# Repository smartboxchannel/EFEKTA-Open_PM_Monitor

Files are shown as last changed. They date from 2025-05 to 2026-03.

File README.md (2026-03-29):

# EFEKTA-Open_PM_Monitor

Описание: http://efektalab.com/Open_PM_Monitor

Поблагодарить автора: https://yoomoney.ru/fundraise/P2XLTgJsB6k.231012

Thank the author: https://yoomoney.ru/fundraise/P2XLTgJsB6k.231012

Телеграм чат DIY Devices - https://t.me/diy_devices

Продажа DIY Устройств - https://t.me/diydevmart

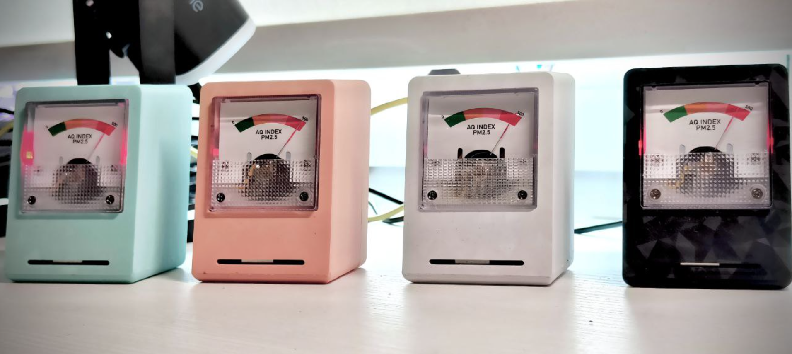
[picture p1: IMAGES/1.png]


Проект датчика мониторинга твердых частиц (PM1.0, PM2.5, PM10, PM2.5 Index, (с версии 2.0 TVOC, eCO2, AQI)) с аналоговым стрелочным дисплеем, Zigbee 3.0. Датчик является роутером сети.

Project of particle monitoring sensor (PM1.0, PM2.5, PM10, PM2.5 Index, (from version 2.0 TVOC, eCO2, AQI)) with analog pointer display, Zigbee 3.0. The sensor is a network router.

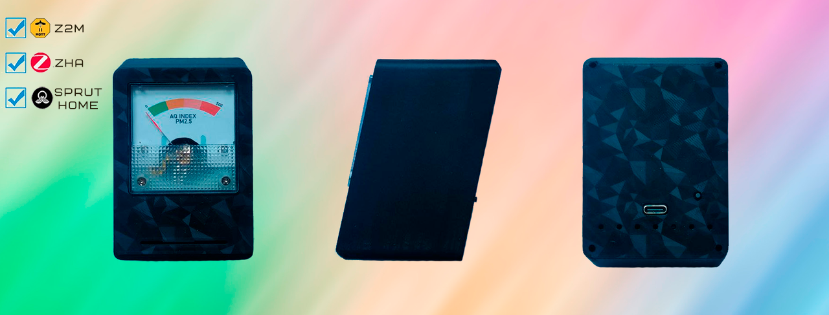
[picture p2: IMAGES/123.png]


Сенсор твердых частиц, помимо данных PM2.5, также измеряет PM1, PM10 и рассчитывает PM2.5 Index. Проект сделан на основе сенсора ASAIR APM10.

The particle sensor, in addition to PM2.5 data, also measures PM1, PM10 and calculates PM2.5 Index. The project is based on the ASAIR APM10 sensor.

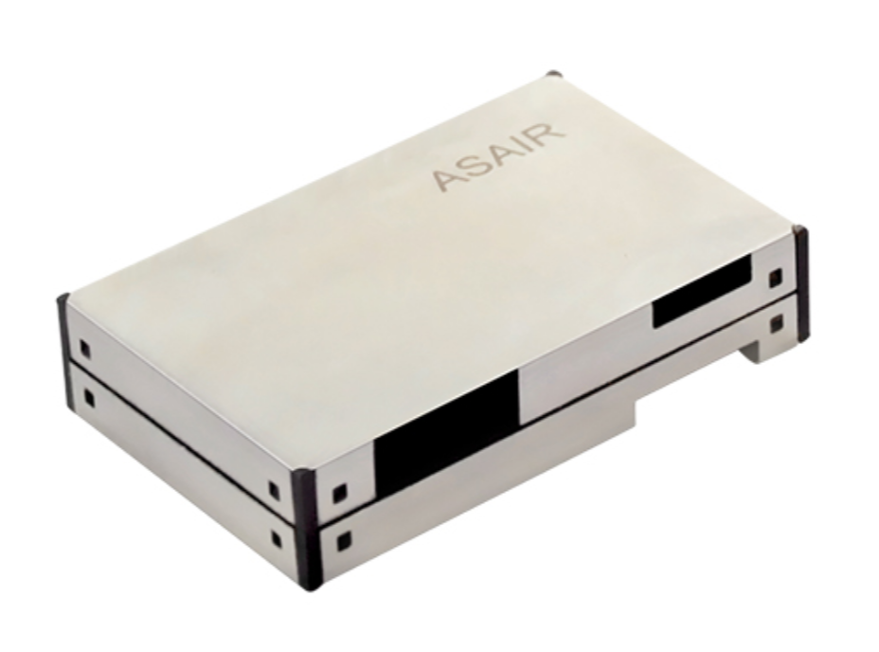
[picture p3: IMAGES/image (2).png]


Помимо стрелочной индикации, есть светодиодная индикация, которая отображает визуально уровень PM2.5 Index. Яркость светодиодов подсветки можно настраивать удалённо. Подсветку также можно отключить удалённо.

In addition to the arrow indication, there is an LED indication that visually displays the PM2.5 Index level. The brightness of the backlight LEDs can be adjusted remotely. The backlight can also be turned off remotely.

#

### Версия 2.0

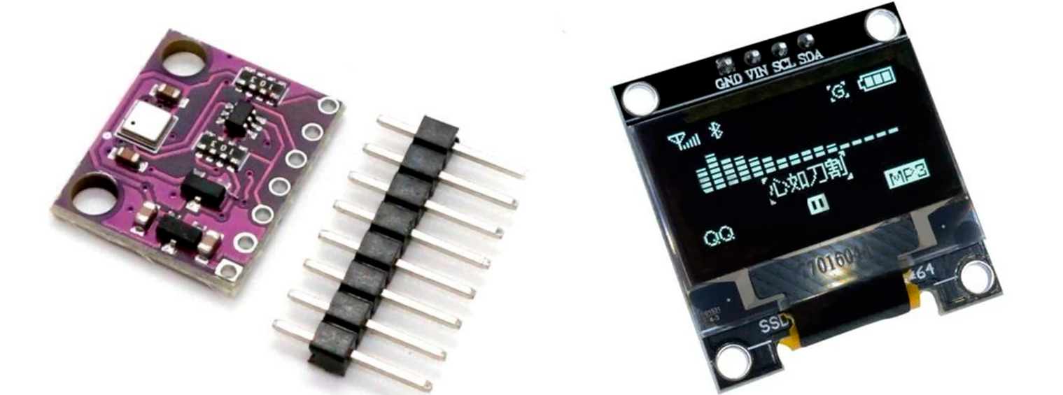
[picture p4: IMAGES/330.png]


В обновленную версию добавлен oled дисплей и сенсор ENS160 (TVOC, eCO2, AQI). Реализовано автоматическое детектирование наличия дисплея и сенсора ENS160, если не подключено что то из этого, работа с дисплеем или сенсором пропускается в ПО. Если подключен сенсор ENS160, на дисплее поочередно выводятся данные PM2.5, TVOC, eCO2. Если сенсор не подключен то выводятся толко данные PM2.5

The updated version includes an OLED display and an ENS160 sensor (TVOC, eCO2, AQI). Automatic detection of the presence of the ENS160 display and sensor has been implemented. If neither of these is connected, operation with the display or sensor is skipped in the software. If the ENS160 sensor is connected, the display alternates between PM2.5, TVOC, and eCO2. If the sensor is not connected, only PM2.5 data is displayed.

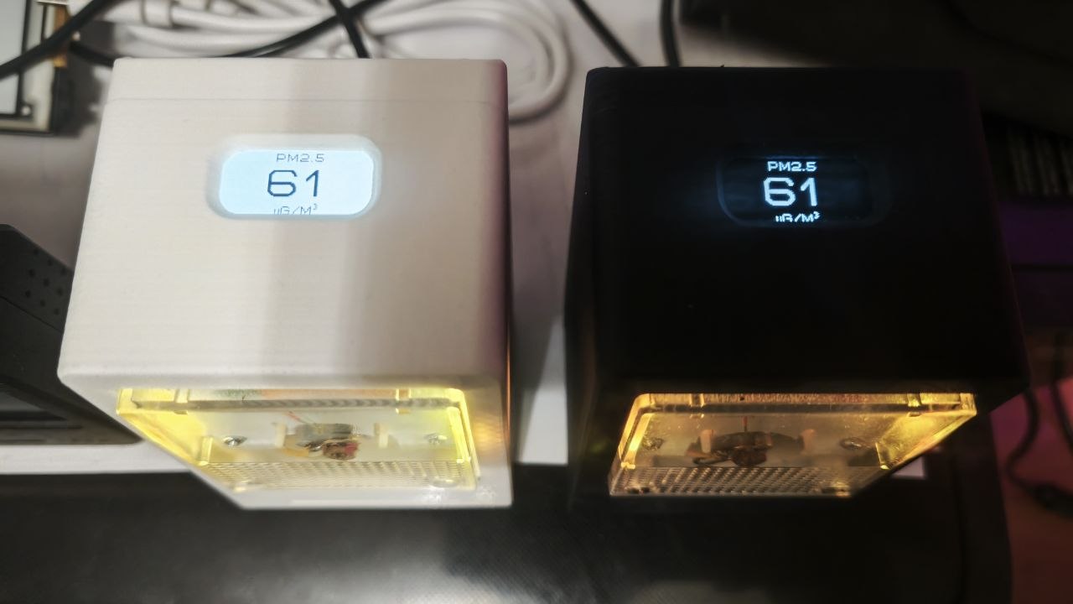
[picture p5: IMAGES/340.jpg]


Добавлена поддержка альтернативного датчика PM того же производителя  - APM2000. В ПО реализовано атоматическое детектирование подключенного сенсора PM.

Added support for an alternative PM sensor from the same manufacturer—the APM2000. The software implements automatic detection of the connected PM sensor.

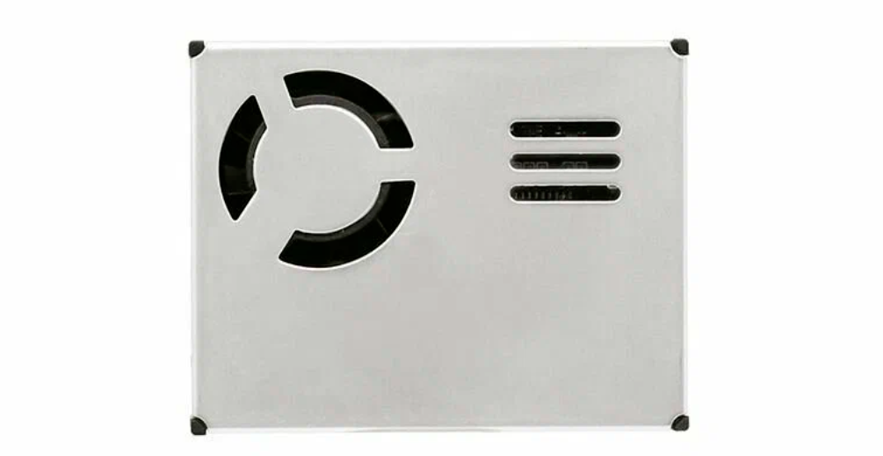
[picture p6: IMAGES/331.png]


## OTA

Датчик может обновляться новыми версиями прошивок по воздуху (OTA).

The sensor can be updated with new firmware versions over the air (OTA). 

( https://github.com/koptserg/OTAClient )

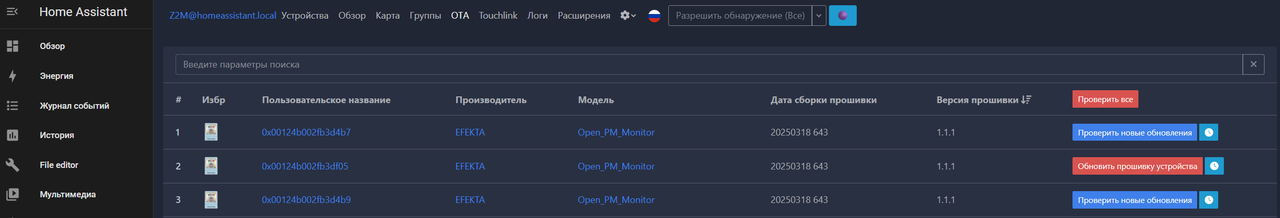
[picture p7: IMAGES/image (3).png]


## Основные данные:

- Identify - идентификация устройства

- State - включение/отключение подсветки

- Brightness - яркость подсветки

- Pm1 - уровень твердых частиц размером 1 мкм и менее

- Pm2.5 - уровень твердых частиц размером 2.5 мкм и менее

- Pm10 - уровень твердых частиц размером 10 мкм и менее

- Aqi25 - индекс качества воздуха на основе PM2.5 (EPA)

- Tvoc - уровень летучих органических соединений

- eCO2 - уровень эквивалента углекислого газа

- AQI - уровень загрязнения воздуха

## Basic data:

- Identify - device identification

- State - backlight on/off

- Brightness - backlight brightness

- Pm1 - particulate matter level of 1 µm or less

- Pm2.5 - particulate matter level of 2.5 µm or less

- Pm10 - particulate matter level of 10 µm or less

- Aqi25 - air quality index based on PM2.5 (EPA)

- Tvoc - Volatile Organic Compounds (VOC)

- eCO2 - Carbon Dioxide Equivalent (CO2)

- AQI - Air Quality Index (AQI)

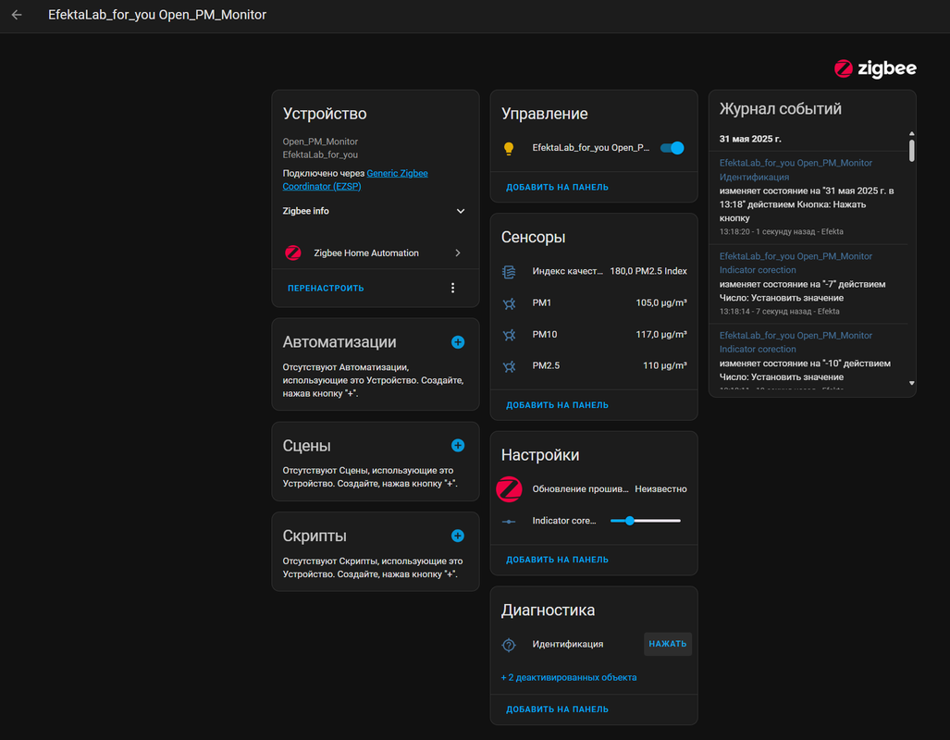
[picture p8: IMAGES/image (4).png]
  

## Конфигурационные данные:

- Indicator correction - подстройка стрелочного индикатора

- Invert color - инвертирование oled дисплея

## Configuration data:

- Indicator correction - adjustment of the arrow indicator

- Invert color - inverting the OLED display

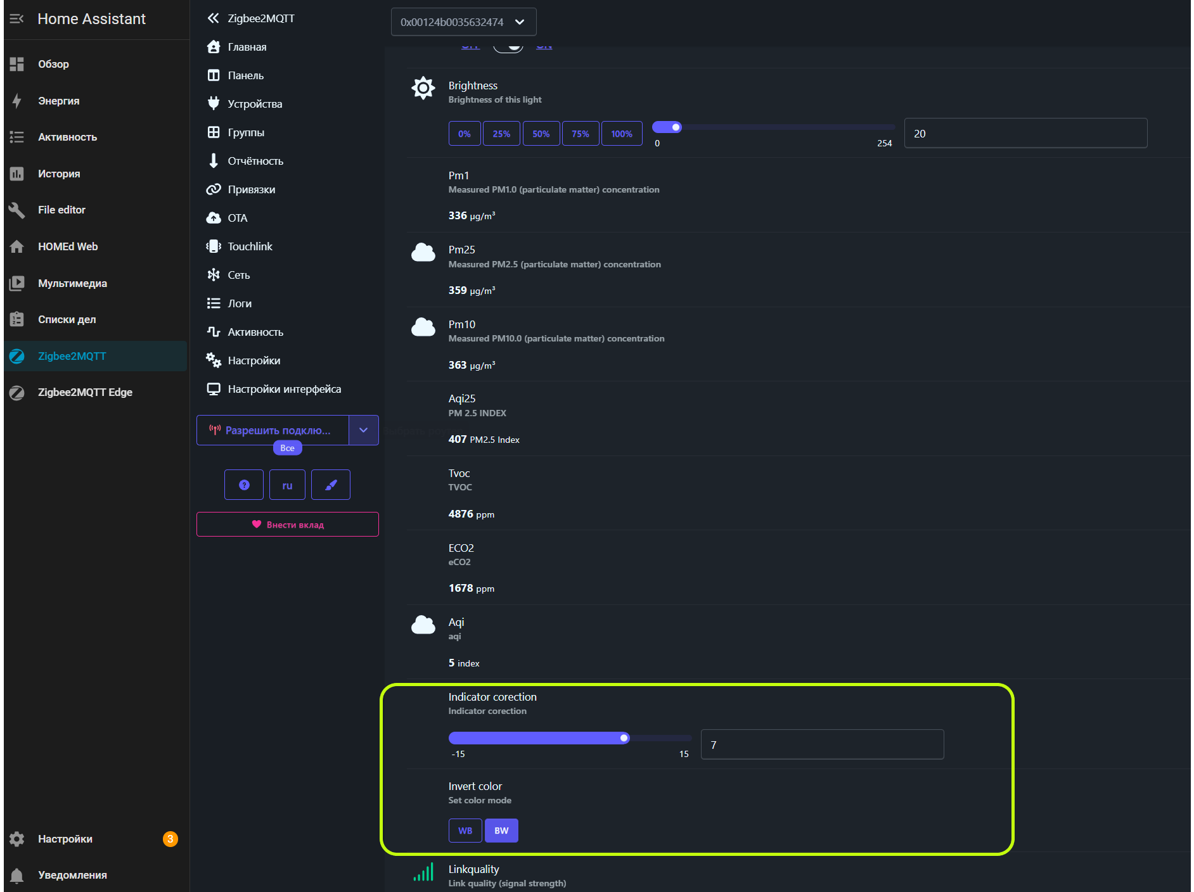
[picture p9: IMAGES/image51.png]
  

## Ввод датчика в сеть, выход из сети

Для джойна (вход в сеть) включите джойн, зажмите и удерживайте кнопку сбоку датчика. С задней стороны датчика загорится системный светодиод (примерно на 3-5 секунд при успешном поиске открытой сети, 15 секунд при неудачном поиске открытой сети).

Если вы не видите на вкладке "Свойства" всех значений конфигурационных атрибутов (пустые поля, переключатели в неопределённом состоянии) или на вкладке "Отчёты" нет заполненных строк о типах данных PM и т.д., то скорее всего конфигурация, которая следует сразу за интервью, не была пройдена до конца.

Для повторного прохождения конфигурации перейдите на главную страницу z2m, найдите строку датчика и справа нажмите на кнопку "Реконфигурация" (жёлтая кнопка), после этого несколько раз нажмите на кнопку джойстик сбоку - это вызовет отправку всех основных и конфигурационных данных. При успешном прохождении конфигурации в интерфейсе z2m должно появиться всплывающее сообщение об успешно пройденной реконфигурации. В разделе датчика на вкладке "Свойства" должны появиться значения и установки всех конфигурационных свойств, на странице "Отчёты" должны появиться строки с конфигурационными настройками отчётов.

Когда датчик в сети, то короткое нажатие на кнопку вызывает процедуру чтения всех сенсоров не по расписанию и отправку данных не в режиме настроенных отчётов.

Для выхода из сети зажмите кнопку на 10 секунд. С задней стороны датчика начнёт мигать системный светодиод (частота переключения LED - 1 секунда). Когда светодиод перестанет мигать, кнопку можно отпустить. Датчик отправит сообщение о выходе из сети, сотрёт у себя все настройки в памяти.

Также выйти из сети можно, удалив датчик из z2m без опции "force remove".

## Entering the sensor into the network, leaving the network

For joining (entering the network), turn on the join, press and hold the button on the side of the sensor. The system LED on the back of the sensor will light up (for about 3-5 seconds if the search for an open network is successful, 15 seconds if the search for an open network is unsuccessful).

If you do not see all the values of the configuration attributes on the "Properties" tab (empty fields, switches in an undefined state) or there are no filled lines on the "Reports" tab about the PM data types, etc., then most likely the configuration that immediately follows the interview was not completed.

To repeat the configuration, go to the main page of z2m, find the sensor line and click on the "Reconfiguration" button on the right (yellow button), then press the joystick button on the side several times - this will cause all the main and configuration data to be sent. If the configuration is successful, a pop-up message about the successful reconfiguration should appear in the z2m interface. In the sensor section, on the "Properties" tab, the values and settings of all configuration properties should appear, and on the "Reports" page, lines with the configuration settings of reports should appear.

When the sensor is online, a short press on the button causes the procedure of reading all sensors not according to the schedule and sending data not in the configured reports mode.

To exit the network, hold the button for 10 seconds. The system LED on the back of the sensor will start blinking (LED switching frequency is 1 second). When the LED stops blinking, you can release the button. The sensor will send a message about leaving the network, erasing all settings in its memory.

You can also exit the network by deleting the sensor from z2m without the "force remove" option.

# Цветовая индикация 

## Индекс качества воздуха на основе PM2.5:

- < 120 - зелёный
- ≥120 < 250 - жёлтый
- ≥250 < 380 - розовый
- ≥380 - красный

# Color indication

## Air quality index based on PM2.5:

- < 120 - green
- ≥120 < 250 - yellow
- ≥250 < 380 - pink
- ≥380 - red

# Обновление ПО (OTA):

Прошивка устройства может быть обновлена. Если для датчика доступно обновление, то необходимо активировать загрузку обновления.

## Если обновление еще не доступно в zigbee2mqtt

Для добавления нового обновления в z2m в "ручную" необходимо:

1. Загрузить в папку zigbee2mqtt файл обновления для датчика, пример /zigbee2mqtt/5678-1000-10063202.zigbee

2. Создать файл ota_index.json с содержанием:

[

  {

    "url": "5678-1000-10063202.zigbee"

  }

]

3. Загрузить файл ota_index.json в папку zigbee2mqtt

4. Перезагрузить zigbee2mqtt

# Software update (OTA):

The device firmware can be updated. If an update is available for the sensor, you must activate the update download.

## If the update is not yet available in zigbee2mqtt

To add a new update to z2m "manually" you need to:

1. Upload the update file for the sensor to the zigbee2mqtt folder, example /zigbee2mqtt/5678-1000-10063202.zigbee

2. Create the ota_index.json file with the content:

[

{

"url": "5678-1000-10063202.zigbee"

}

]

3. Upload the ota_index.json file to the zigbee2mqtt folder

4. Restart zigbee2mqtt

#

### Установка среды разработки

В качестве среды разработки будет использоваться IAR Embedded Workbench, где цифра 8051 это архитектура чипа, а не версия системы, как можно подумать. Для начала необходимо ее [скачать по ссылке](https://www.iar.com/iar-embedded-workbench#!?architecture=8051)

MODKAM Flower 

Запускаем, необходимо выбрать пункт "Install IAR Embedded Workbench® for 8051"

MODKAM Flower 

При установке iar надо выбрать режим custom:

MODKAM Flower 

и убрать галочку с установки Dongle drivers

MODKAM Flower 

При попытки запуска проекта может быть такая ошибка:

MODKAM Flower 

Поэтому перед запуском проекта необходимо убедиться что python установлен. Проверить это можно в командной строке:

python –-version

MODKAM Flower 

Если все хорошо, то покажет текущую установленную версию python, как на примере:

MODKAM Flower 

Если же нет, то [идем устанавливать python](https://www.python.org/)

MODKAM Flower 

Устанавливаем его. Обязательно необходимо проставить галочку "add python **** to path"

MODKAM Flower 

Устанавливаем прошивку [Z-Stack 3.0.2](https://www.ti.com/tool/Z-STACK) — это SDK для разработки прошивок.

MODKAM Flower 

Устанавливаем, можно немного уменьшить путь до zstack: C:\Z-Stack 3.0.2. 

Скачиваем исходный код из репозитория

Добавляем папку с файлами проекта в zstack: C:\Z-Stack 3.0.2\Projects\zstack\HomeAutomation

Теперь можно запускать IAR Embedded Workbench. Открываем проект пунктом меню Open workspace

MODKAM Flower 

Находим нашу папку со скаченным проектом, далее в папке CC2530DB находим файл проекта

MODKAM Flower 

Выполняем Rebuild All.

MODKAM Flower 

#

### Как прошить устройство

Скачайте Smart RF Flash Programmer V1 https://www.ti.com/tool/FLASH-PROGRAMMER

Откройте приложение, выберите HEX-файл прошивки

Подключите устройство проводами к CCDebugger, сначала сотрите данные с чипа, затем прошейте его.

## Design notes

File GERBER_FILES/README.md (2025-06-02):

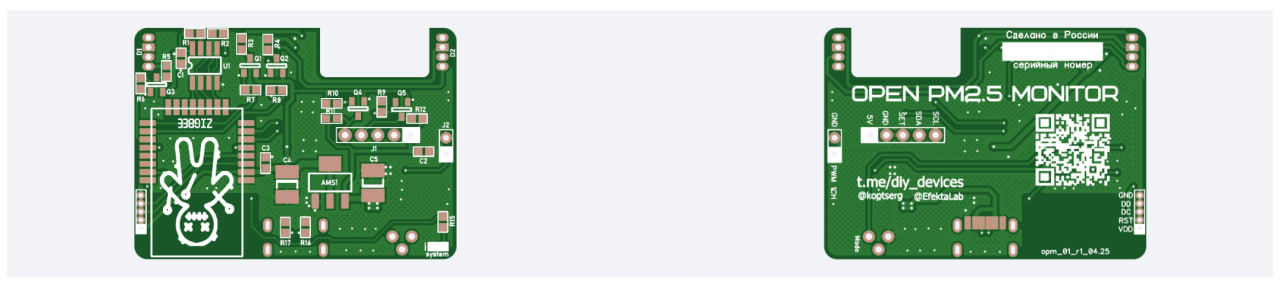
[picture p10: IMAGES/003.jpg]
EFEKTA Open PM Monitor


### pcb 1.6mm

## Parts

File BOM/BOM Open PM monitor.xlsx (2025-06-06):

Comment | Designator | АлиЭкспресс | Zigbee-Shop
M25PE20-VMN6TP | U1 | https://aliexpress.ru/item/1005008415017340.html
E18-MS1PA2-IPX | U2 | https://aliexpress.ru/item/4000818220197.html | Беспроводной модуль EBYTE E18-MS1PA2-IPEX ZigBee - ZigBee-Shop.ru (https://zigbee-shop.ru/catalog/goods/1444)
AMS1117 | U3 | https://aliexpress.ru/item/1005008229056966.html | Стабилизатор AMS1117 3.3V - ZigBee-Shop.ru (https://zigbee-shop.ru/catalog/goods/1132)
100NF 0603 | C1, C2, С3 | https://aliexpress.ru/item/1005002063634783.html | Чип конденсатор (SMD) 0603 100NF 0.1uF - ZigBee-Shop.ru (https://zigbee-shop.ru/catalog/goods/1548)
51Ω 0603 | R3 | https://aliexpress.ru/item/1005008917262490.html | Чип резистор (SMD) 0603 51R, 1% - ZigBee-Shop.ru (https://zigbee-shop.ru/catalog/goods/1794)
200Ω 0603 | R5 | https://aliexpress.ru/item/32997843929.html | Чип резистор (SMD) 0603 200R, 5% - ZigBee-Shop.ru (https://zigbee-shop.ru/catalog/goods/1754)
470Ω 0603 | R4 | https://aliexpress.ru/item/1005001793580277.html | Чип резистор (SMD) 0603 470R, 5% - ZigBee-Shop.ru (https://zigbee-shop.ru/catalog/goods/1544)
1KΩ 0603 | R5, R7, R8 | https://aliexpress.ru/item/1005008633246937.html | Чип резистор (SMD) 0603 1K, 5% - ZigBee-Shop.ru (https://zigbee-shop.ru/catalog/goods/1210)
2KΩ 0603 | R1, R2 | https://aliexpress.ru/item/1005008810795724.html | Чип резистор (SMD) 0603 2.4K, 5% - ZigBee-Shop.ru (https://zigbee-shop.ru/catalog/goods/1212)
4.2KΩ 0603 | R15 | https://aliexpress.ru/item/1005008533807204.html | Чип резистор (SMD) 0603 4.7K, 5% - ZigBee-Shop.ru (https://zigbee-shop.ru/catalog/goods/1211)
5.1KΩ 0603 | R16, R17 | https://aliexpress.ru/item/1005004538763316.html | Чип резистор (SMD) 0603 5.1K, 5% - ZigBee-Shop.ru (https://zigbee-shop.ru/catalog/goods/1546)
10KΩ 0603 | R9, R10, R11, R12 | https://aliexpress.ru/item/1005004541262069.html | Чип резистор (SMD) 0603 10K, 5% - ZigBee-Shop.ru (https://zigbee-shop.ru/catalog/goods/1545)
TCAP 22UF | C4, C5 | https://aliexpress.ru/item/1005008695997250.html | Танталовый конденсатор 22UF 16V CASE-B TAJB226K016RNJ - ZigBee-Shop.ru (https://zigbee-shop.ru/catalog/goods/1178)
USB C 6P | U2 | https://aliexpress.ru/item/1005006047551075.html | Разъем TYPE-C 6 Pin SMT - ZigBee-Shop.ru (https://zigbee-shop.ru/catalog/goods/1539)
S8050 | Q1, Q2, Q3 | https://aliexpress.ru/item/1005008535311819.html | Транзистор SS8050, NPN 25V 1.5A [SOT-23] - ZigBee-Shop.ru (https://zigbee-shop.ru/catalog/goods/1288)
RGB Common Cathode | D1, D2 | https://aliexpress.ru/item/1005003168998839.html
BSS138 | Q4, Q5 | https://aliexpress.ru/item/1005008321377755.html | Транзистор BSS138W, N-канал, 50В, 0.22А [SOT-323] - ZigBee-Shop.ru (https://zigbee-shop.ru/catalog/goods/1921)
Switch 4.5x4.5 8mm | KEY1 | https://aliexpress.ru/item/1005007935339142.html
Led 0604 | LED1 | https://aliexpress.ru/item/1005003523838944.html
Voltmeter 3V |  | https://aliexpress.ru/item/32617041101.html
PM ASAIR APM10 |  | https://aliexpress.ru/item/1005006514171610.html
Антенна 2.4 IPEX |  | https://aliexpress.ru/item/1005005324850574.html | Антенна липучка IPEX 10 см - ZigBee-Shop.ru (https://zigbee-shop.ru/catalog/goods/1653)
Саморезы M1.4 5мм |  | https://aliexpress.ru/item/32835249403.html

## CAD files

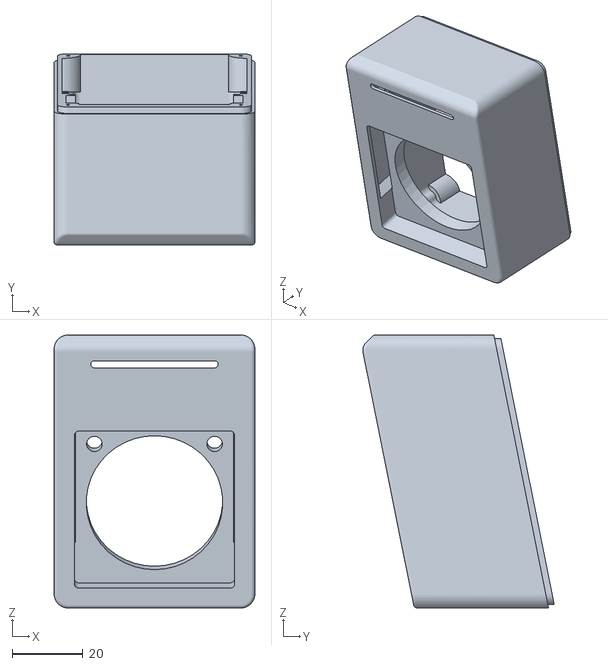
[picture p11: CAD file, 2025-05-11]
ENCLOUSER/1.stl
56.8 x 54.1 x 77.2

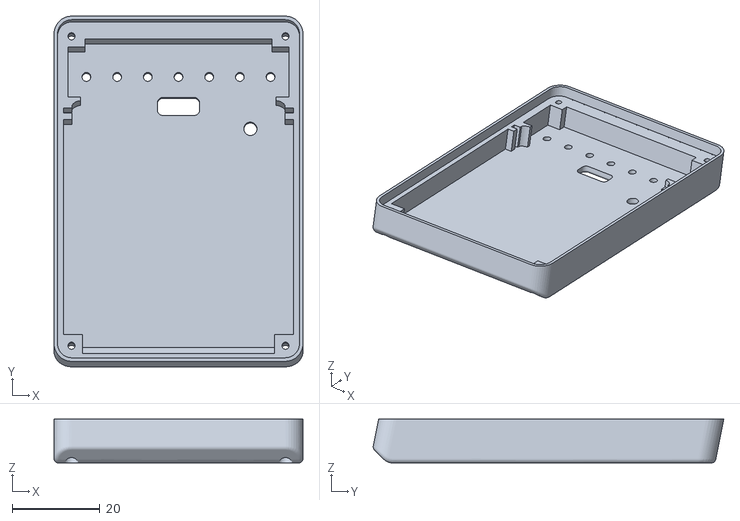
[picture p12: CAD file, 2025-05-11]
ENCLOUSER/2.stl
56.8 x 80.0 x 10.0

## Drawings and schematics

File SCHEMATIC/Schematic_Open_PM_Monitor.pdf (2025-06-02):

## R8PWM³Ch

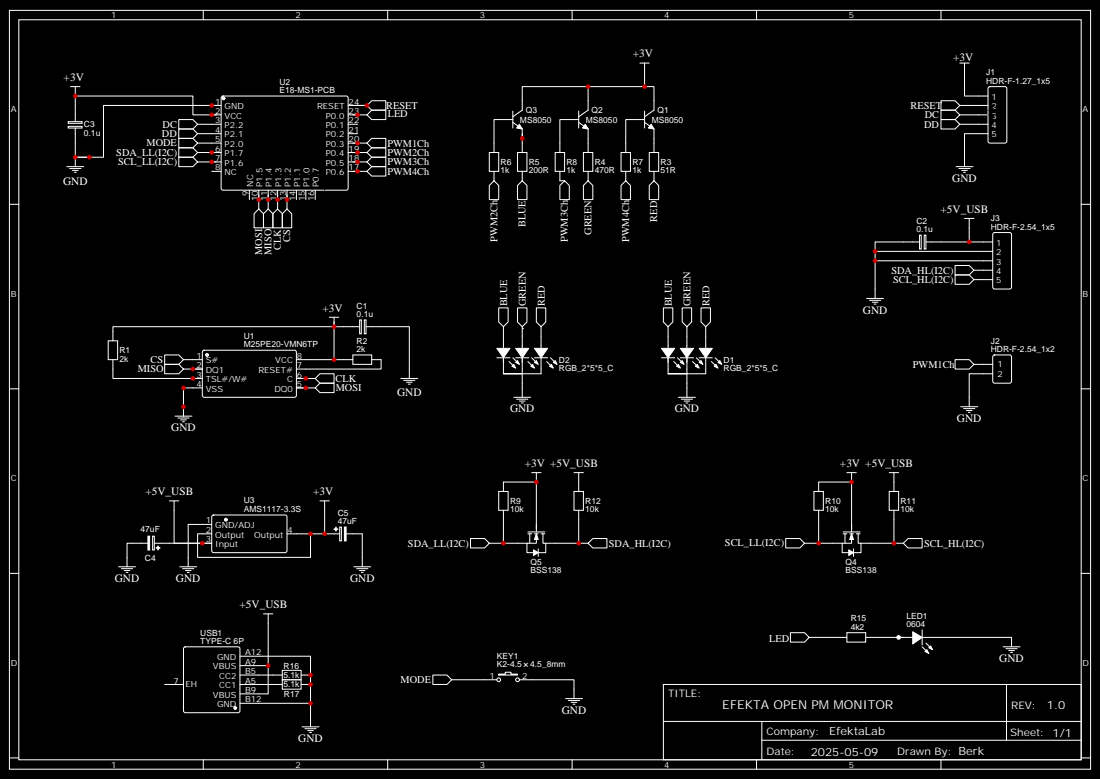
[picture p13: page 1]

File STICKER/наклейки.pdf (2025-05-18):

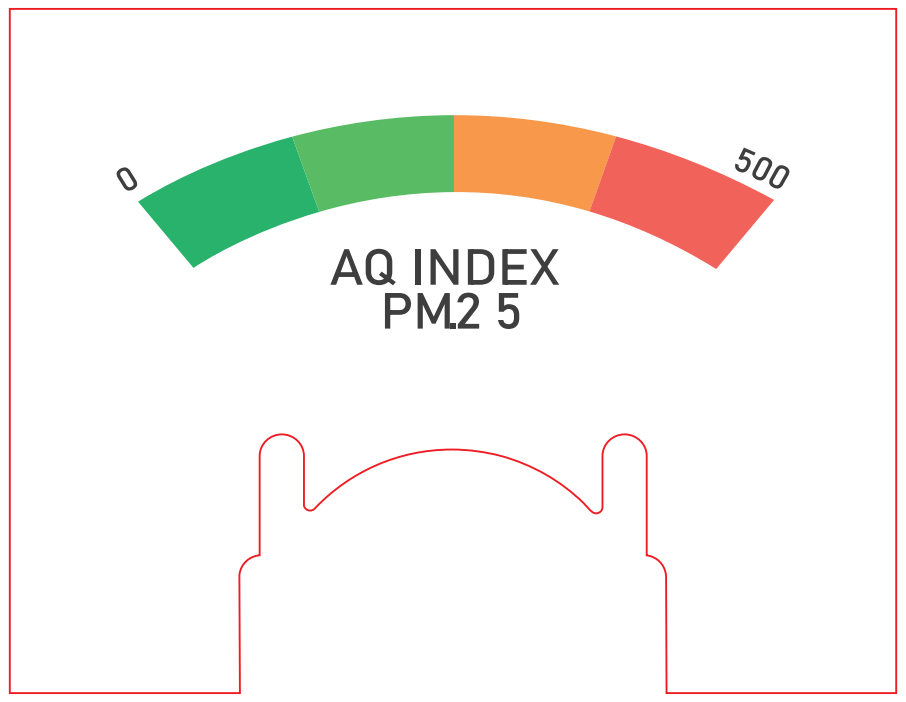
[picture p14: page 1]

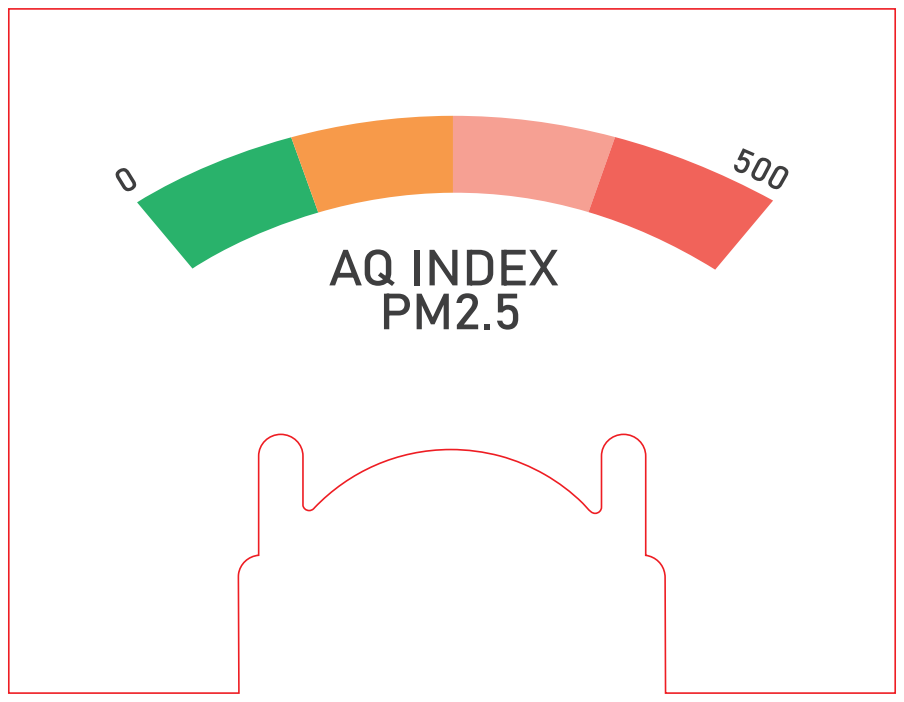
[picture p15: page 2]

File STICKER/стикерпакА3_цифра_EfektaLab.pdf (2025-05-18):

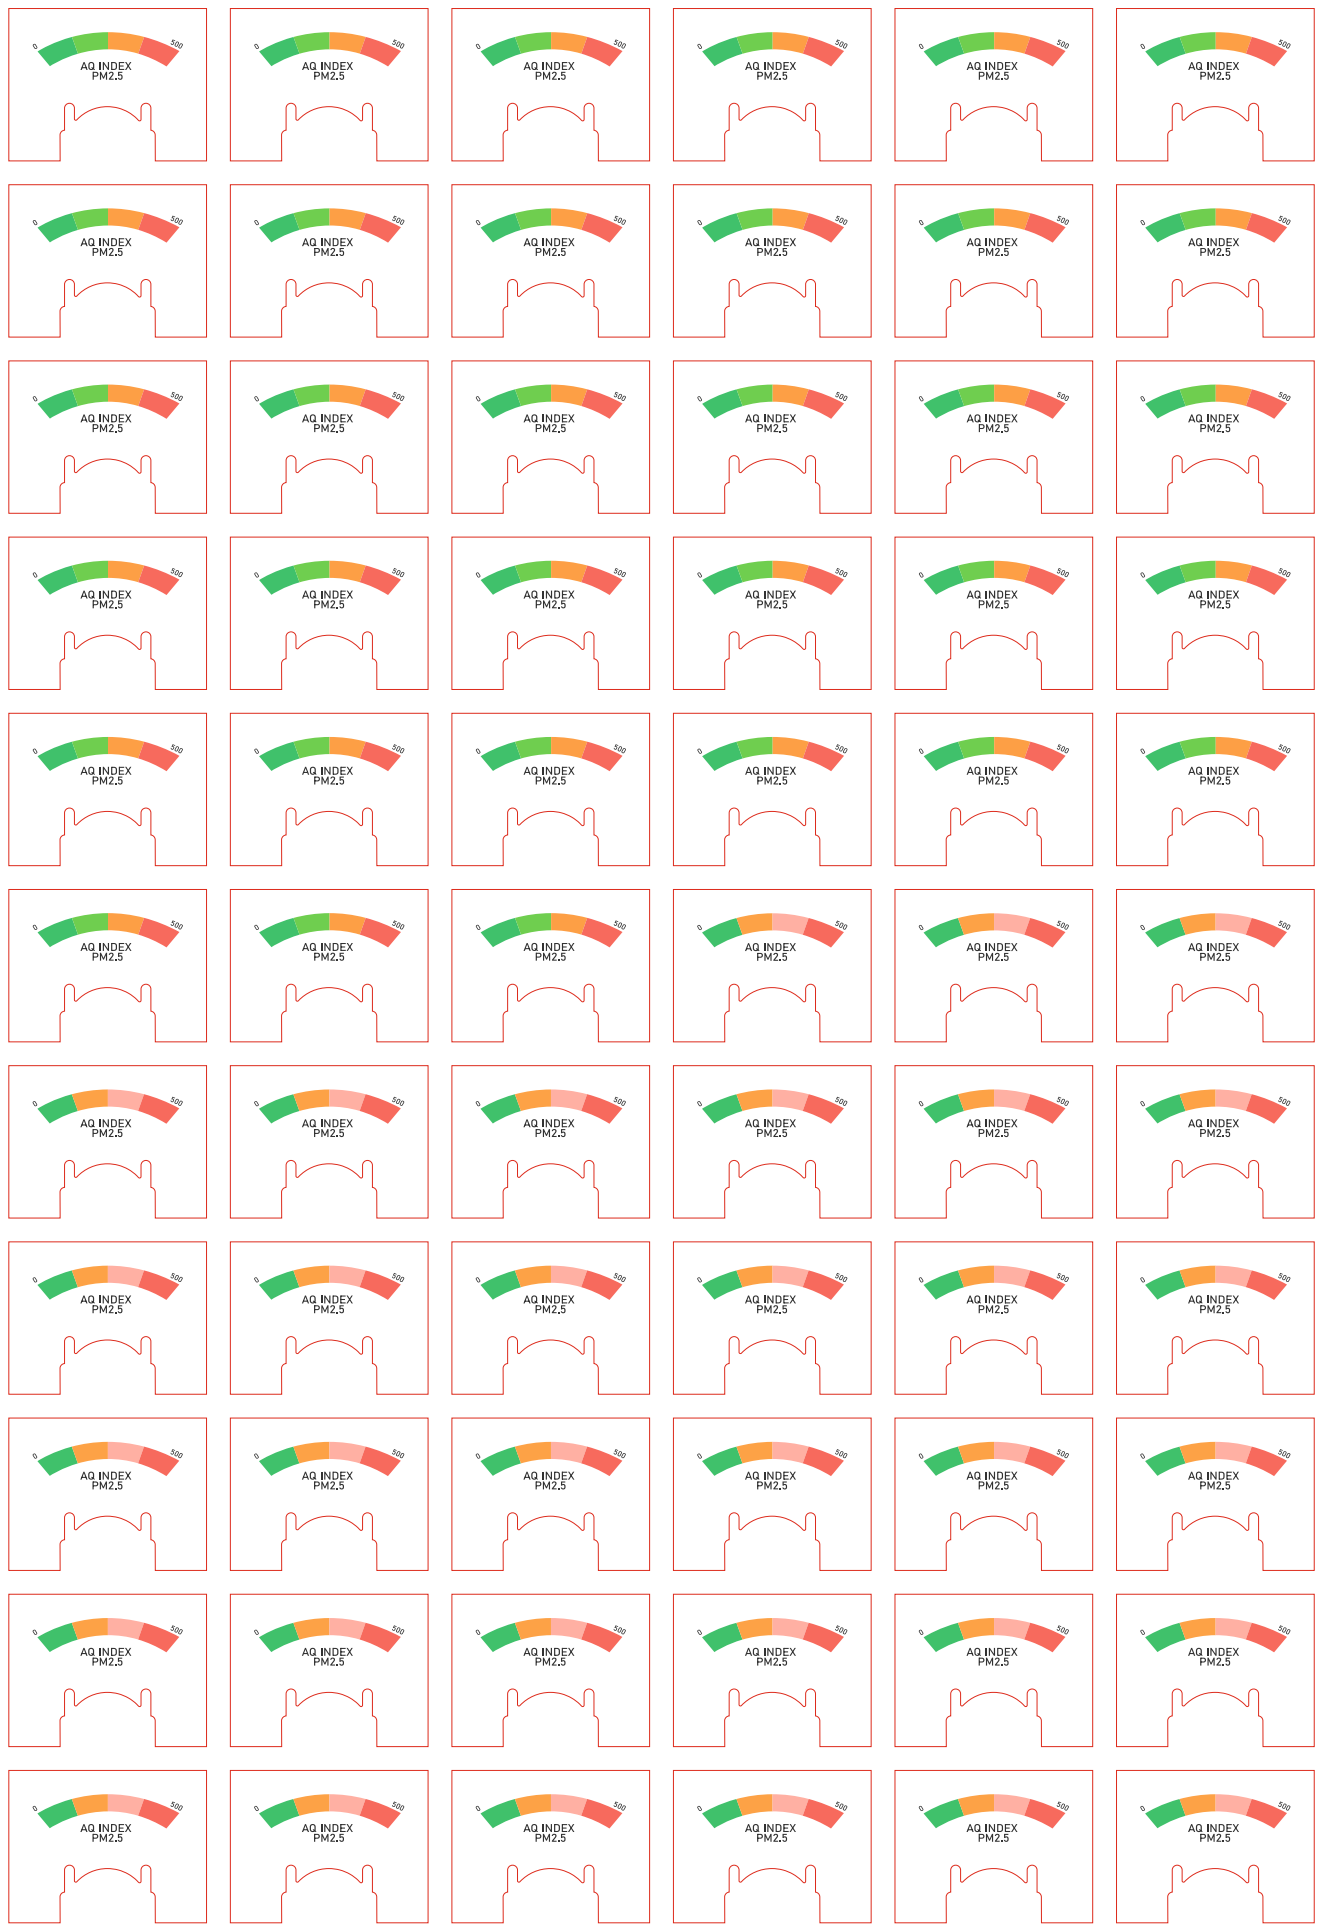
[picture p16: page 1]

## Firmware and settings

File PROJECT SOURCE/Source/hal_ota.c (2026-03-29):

/******************************************************************************
  Filename:       hal_ota.c
  Revised:        $Date: 2010-11-18 08:22:50 -0800 (Thu, 18 Nov 2010) $
  Revision:       $Revision: 24438 $

  Description:    This module contains optionally-compiled Boot Code to support
                  OTA. The rest of the functionality is the H/W specific drivers
                  to read/write the flash/NV containing the ACTIVE and the
                  DOWNLOADED images.
  Notes:          Targets the Texas Instruments CC253x family of processors.


  Copyright 2010 Texas Instruments Incorporated. All rights reserved.

  IMPORTANT: Your use of this Software is limited to those specific rights
  granted under the terms of a software license agreement between the user
  who downloaded the software, his/her employer (which must be your employer)
  and Texas Instruments Incorporated (the "License").  You may not use this
  Software unless you agree to abide by the terms of the License. The License
  limits your use, and you acknowledge, that the Software may not be modified,
  copied or distributed unless embedded on a Texas Instruments microcontroller
  or used solely and exclusively in conjunction with a Texas Instruments radio
  frequency transceiver, which is integrated into your product.  Other than for
  the foregoing purpose, you may not use, reproduce, copy, prepare derivative
  works of, modify, distribute, perform, display or sell this Software and/or
  its documentation for any purpose.

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
  Should you have any questions regarding your right to use this Software,
  contact Texas Instruments Incorporated at www.TI.com.
******************************************************************************/

/******************************************************************************
 * INCLUDES
 */
#include "comdef.h"
#include "hal_board_cfg.h"
#include "hal_dma.h"
#include "hal_flash.h"
#include "hal_ota.h"
#include "hal_types.h"

#include "ota_common.h"

//#include "Debug.h"
#include "OSAL.h"
/******************************************************************************
 * CONSTANTS
 */
#if HAL_OTA_XNV_IS_SPI
/*
#define XNV_STAT_CMD  0x05
#define XNV_WREN_CMD  0x06
#define XNV_WRPG_CMD  0x0A
//#define XNV_WRPG_CMD  0x02
#define XNV_READ_CMD  0x0B //READ DATA BYTES at HIGHER SPEED
//#define XNV_READ_CMD  0x03 //READ DATA BYTES
#define XNV_STAT_WIP  0x01
#define XNV_BE_CMD    0xC7
*/
#define XNV_STAT_CMD  0x05
#define XNV_WREN_CMD  0x06
#define XNV_WRPG_CMD  0x02
#define XNV_READ_CMD  0x0B //READ DATA BYTES at HIGHER SPEED
#define XNV_STAT_WIP  0x00
#define XNV_BE_CMD    0xC7
#define XNV_SE_CMD    0x20 // SECTOR ERASE 4K

#define ERASE_SECTOR_SIZE 0x1000  // 4 KB

static uint32 lastErased = 0xFFFFFFFF;
#endif

/******************************************************************************
 * TYPEDEFS
 */
typedef struct
{
  uint16 crc[2];
  uint32 programSize;
} OTA_CrcControl_t;

/******************************************************************************
 * LOCAL VARIABLES
 */
OTA_CrcControl_t OTA_crcControl;

#if HAL_OTA_BOOT_CODE
halDMADesc_t dmaCh0;
#endif

/******************************************************************************
 * LOCAL FUNCTIONS
 */
static uint16 runPoly(uint16 crc, uint8 val);

#if HAL_OTA_XNV_IS_SPI
static void HalSPIRead(uint32 addr, uint8 *pBuf, uint16 len);
static void HalSPIWrite(uint32 addr, uint8 *pBuf, uint16 len);
static void xnvSPIWrite(uint8 ch);
static void HalSPIEraseSector4K(uint32 addr);
static void DelayMs(uint16 delaytime);
#endif


#if HAL_OTA_BOOT_CODE
static void dl2rc(void);
static uint16 crcCalc(void);

/******************************************************************************
 * @fn      main
 *
 * @brief   ISR for the reset vector.
 *
 * @param   None.
 *
 * @return  None.
 */
#pragma location="NEAR_CODE"
void main(void)
{
  HAL_BOARD_INIT();
#if HAL_OTA_XNV_IS_SPI
  XNV_SPI_INIT();
#endif
  /* This is in place of calling HalDmaInit() which would require init of the
   * other 4 DMA descriptors in addition to just Channel 0.
   */
  HAL_DMA_SET_ADDR_DESC0( &dmaCh0 );

  while (1)
  {
    HalFlashRead(HAL_OTA_CRC_ADDR / HAL_FLASH_PAGE_SIZE,
                 HAL_OTA_CRC_ADDR % HAL_FLASH_PAGE_SIZE,
                 (uint8 *)&OTA_crcControl, sizeof(OTA_crcControl));

    if (OTA_crcControl.crc[0] == OTA_crcControl.crc[1])
    {
      break;
    }
    else if ((OTA_crcControl.crc[0] != 0) && (OTA_crcControl.crc[0] == crcCalc()))
    {
      OTA_crcControl.crc[1] = OTA_crcControl.crc[0];
      HalFlashWrite((HAL_OTA_CRC_ADDR / HAL_FLASH_WORD_SIZE), (uint8 *)OTA_crcControl.crc, 1);
    }
    else
    {
      dl2rc();
    }
  }

  // Simulate a reset for the Application code by an absolute jump to location 0x0800.
  asm("LJMP 0x800\n");
}

/******************************************************************************
 * @fn      dl2rc
 *
 * @brief   Copy the DL image to the RC image location.
 *
 *  NOTE:   Assumes that DL image ends on a flash word boundary.
 *
 * @param   None.
 *
 * @return  None.
 */
static void dl2rc(void)
{
  uint32 oset;
  OTA_SubElementHdr_t subElement;
  OTA_ImageHeader_t header;
  uint16 addr = HAL_OTA_RC_START / HAL_FLASH_WORD_SIZE;
  uint8 buf[4];

  // Determine the length and starting point of the upgrade image
  HalOTARead(0, (uint8 *)&header, sizeof(OTA_ImageHeader_t), HAL_OTA_DL);
  HalOTARead(header.headerLength, (uint8*)&subElement, OTA_SUB_ELEMENT_HDR_LEN, HAL_OTA_DL);

  for (oset = 0; oset < subElement.length; oset += HAL_FLASH_WORD_SIZE)
  {
    HalOTARead(oset + header.headerLength + OTA_SUB_ELEMENT_HDR_LEN, buf, HAL_FLASH_WORD_SIZE, HAL_OTA_DL);
    if ((addr % (HAL_FLASH_PAGE_SIZE / HAL_FLASH_WORD_SIZE)) == 0)
    {
      HalFlashErase(addr / (HAL_FLASH_PAGE_SIZE / HAL_FLASH_WORD_SIZE));
    }
    HalFlashWrite(addr++, buf, 1);
  }
}

/******************************************************************************
 * @fn      crcCalc
 *
 * @brief   Run the CRC16 Polynomial calculation over the RC image.
 *
 * @param   None.
 *
 * @return  The CRC16 calculated.
 */
static uint16 crcCalc()
{
  uint32 oset;
  uint16 crc = 0;

  // Run the CRC calculation over the active body of code.
  for (oset = 0; oset < OTA_crcControl.programSize; oset++)
  {
    if ((oset < HAL_OTA_CRC_OSET) || (oset >= HAL_OTA_CRC_OSET + 4))
    {
      uint8 buf;
      HalOTARead(oset, &buf, 1, HAL_OTA_RC);
      crc = runPoly(crc, buf);
    }
  }

  return crc;
}
#endif //HAL_OTA_BOOT_CODE

/******************************************************************************
 * @fn      runPoly
 *
 * @brief   Run the CRC16 Polynomial calculation over the byte parameter.
 *
 * @param   crc - Running CRC calculated so far.
 * @param   val - Value on which to run the CRC16.
 *
 * @return  crc - Updated for the run.
 */
static uint16 runPoly(uint16 crc, uint8 val)
{
  const uint16 poly = 0x1021;
  uint8 cnt;

  for (cnt = 0; cnt < 8; cnt++, val <<= 1)
  {
    uint8 msb = (crc & 0x8000) ? 1 : 0;

    crc <<= 1;
    if (val & 0x80)  crc |= 0x0001;
    if (msb)         crc ^= poly;
  }

  return crc;
}

/******************************************************************************
 * @fn      HalOTAChkDL
 *
 * @brief   Run the CRC16 Polynomial calculation over the DL image.
 *
 * @param   None
 *
 * @return  SUCCESS or FAILURE.
 */
uint8 HalOTAChkDL(uint8 dlImagePreambleOffset)
{
 (void)dlImagePreambleOffset;  // Intentionally unreferenced parameter

  uint32 oset;
  uint16 crc = 0;
  OTA_CrcControl_t crcControl;
  OTA_ImageHeader_t header;
  uint32 programStart;

#if HAL_OTA_XNV_IS_SPI
  XNV_SPI_INIT();
#endif

  // Read the OTA File Header
  HalOTARead(0, (uint8 *)&header, sizeof(OTA_ImageHeader_t), HAL_OTA_DL);

  // Calculate the update image start address
  programStart = header.headerLength + OTA_SUB_ELEMENT_HDR_LEN; // 0x38 + 0x06 = 0x3E
  
  uint8 raw[16];
  HalOTARead(0, raw, 16, HAL_OTA_DL);
  //LREP("magicNumber=0x%02X%02X%02X%02X\r\n", raw[3], raw[2], raw[1], raw[0]); //32
//  LREP("headerVersion=0x%02X%02X\r\n", raw[5], raw[4]); //16
//  LREP("headerLength=0x%02X%02X\r\n", raw[7], raw[6]); //16
//  LREP("fieldControl=0x%02X%02X\r\n", raw[9], raw[8]); //16
  
  uint8 raw1[4];
  osal_buffer_uint32(raw1, programStart + HAL_OTA_CRC_OSET ); // 0x3E + 0x88 = 0xC6
  //LREP("prStart+CRC_OSET =0x%02X%02X%02X%02X\r\n", raw1[3], raw1[2], raw1[1], raw1[0]); //32
  
  // Get the CRC Control structure
  HalOTARead(programStart + HAL_OTA_CRC_OSET, (uint8 *)&crcControl, sizeof(crcControl), HAL_OTA_DL);
  
  uint8 raw2[8];
  HalOTARead(programStart + HAL_OTA_CRC_OSET, raw2, 8, HAL_OTA_DL);
  //LREP("crcC.crc =0x%02X%02X%02X%02X\r\n", raw2[3], raw2[2], raw2[1], raw2[0]); //32
  //LREP("crcC.prSize =0x%02X%02X%02X%02X\r\n", raw2[7], raw2[6], raw2[5], raw2[4]); //32
  
//  memset(bytes, 0, 4 * sizeof(uint8));
//  osal_buffer_uint32( bytes, HAL_OTA_DL_MAX );
//  LREP("HAL_OTA_DL_MAX =0x%02X%02X%02X%02X\r\n", bytes[3], bytes[2], bytes[1], bytes[0]);

  if ((crcControl.programSize > HAL_OTA_DL_MAX) || (crcControl.programSize == 0))
  {
    return FAILURE;
  }

  // Run the CRC calculation over the downloaded image.
  for (oset = 0; oset < crcControl.programSize; oset++)
  {
    if ((oset < HAL_OTA_CRC_OSET) || (oset >= HAL_OTA_CRC_OSET+4))
    {
      uint8 buf;
      HalOTARead(oset + programStart, &buf, 1, HAL_OTA_DL);
      crc = runPoly(crc, buf);
    }
  }

  return (crcControl.crc[0] == crc) ? SUCCESS : FAILURE;
}

/******************************************************************************
 * @fn      HalOTAInvRC
 *
 * @brief   Invalidate the active image so that the boot code will instantiate
 *          the DL image on the next reset.
 *
 * @param   None.
 *
 * @return  None.
 */
void HalOTAInvRC(void)
{
  uint16 crc[2] = {0,0xFFFF};
  HalFlashWrite((HAL_OTA_CRC_ADDR / HAL_FLASH_WORD_SIZE), (uint8 *)crc, 1);
}

/******************************************************************************
 * @fn      HalOTARead
 *
 * @brief   Read from the storage medium according to image type.
 *
 * @param   oset - Offset into the monolithic image.
 * @param   pBuf - Pointer to the buffer in which to copy the bytes read.
 * @param   len - Number of bytes to read.
 * @param   type - Which image: HAL_OTA_RC or HAL_OTA_DL.
 *
 * @return  None.
 */
void HalOTARead(uint32 oset, uint8 *pBuf, uint16 len, image_t type)
{
  if (HAL_OTA_RC != type)
  {
#if HAL_OTA_XNV_IS_INT
    preamble_t preamble;

    HalOTARead(PREAMBLE_OFFSET, (uint8 *)&preamble, sizeof(preamble_t), HAL_OTA_RC);
    oset += HAL_OTA_RC_START + HAL_OTA_DL_OSET;
#elif HAL_OTA_XNV_IS_SPI
    oset += HAL_OTA_DL_OSET;
    HalSPIRead(oset, pBuf, len);
   
//    LREPMaster("HalOTARead\r\n");
/*    
    uint8 buf[4];
    osal_buffer_uint32( buf, oset );
    LREP("oset=0x%02X%02X%02X%02X\r\n", buf[3], buf[2], buf[1], buf[0]); //32
    LREP("len=%d\r\n", len); //16

    for(uint8 i = 0; i<len; i++){
      LREP("0x%02X\r\n", pBuf[i]);
    }
 */         
    if (oset == 0) {
//      LREP("magicNumber=0x%02X%02X%02X%02X\r\n", pBuf[3], pBuf[2], pBuf[1], pBuf[0]); //32
//      LREP("headerVersion=0x%02X%02X\r\n", pBuf[5], pBuf[4]); //16
//      LREP("headerLength=0x%02X%02X\r\n", pBuf[7], pBuf[6]); //16
//      LREP("fieldControl=0x%02X%02X\r\n", pBuf[9], pBuf[8]); //16
      
//      LREP("imageSize=0x%02X%02X%02X%02X\r\n", pBuf[55-oset], pBuf[54-oset], pBuf[53-oset], pBuf[52-oset]); //32
    }  
    return;
#endif
  }
  else
  {
    oset += HAL_OTA_RC_START;
  }

  HalFlashRead(oset / HAL_FLASH_PAGE_SIZE, oset % HAL_FLASH_PAGE_SIZE, pBuf, len);
}

/******************************************************************************
 * @fn      HalOTAWrite
 *
 * @brief   Write to the storage medium according to the image type.
 *
 *  NOTE:   Destructive write on page boundary! When writing to the first flash word
 *          of a page boundary, the page is erased without saving/restoring the bytes not written.
 *          Writes anywhere else on a page assume that the location written to has been erased.
 *
 * @param   oset - Offset into the monolithic image, aligned to HAL_FLASH_WORD_SIZE.
 * @param   pBuf - Pointer to the buffer in from which to write.
 * @param   len - Number of bytes to write. If not an even multiple of HAL_FLASH_WORD_SIZE,
 *                remainder bytes are overwritten with garbage.
 * @param   type - Which image: HAL_OTA_RC or HAL_OTA_DL.
 *
 * @return  None.
 */

void HalOTAWrite(uint32 oset, uint8 *pBuf, uint16 len, image_t type)
{
  if (HAL_OTA_RC != type)
  {
#if HAL_OTA_XNV_IS_INT
    oset += HAL_OTA_RC_START + HAL_OTA_DL_OSET;
#elif HAL_OTA_XNV_IS_SPI
    
    uint32 eraseStart = oset & ~(ERASE_SECTOR_SIZE - 1);
    if (eraseStart != lastErased) {
      HalSPIEraseSector4K(eraseStart);
      uint8 raw[4];
      osal_buffer_uint32( raw, eraseStart );
      //LREP("[FLASH] ERASE 4K at 0x%02X%02X%02X%02X\r\n", raw[3], raw[2], raw[1], raw[0]);
      lastErased = eraseStart;
    }  
    
    oset += HAL_OTA_DL_OSET;
    HalSPIWrite(oset, pBuf, len);
    
    //LREPMaster("HalOTAWrite\r\n");

    return;
#endif
  }
  else
  {
    oset += HAL_OTA_RC_START;
  }

  if ((oset % HAL_FLASH_PAGE_SIZE) == 0)
  {
    HalFlashErase(oset / HAL_FLASH_PAGE_SIZE);
  }

  HalFlashWrite(oset / HAL_FLASH_WORD_SIZE, pBuf, len / HAL_FLASH_WORD_SIZE);
}

/******************************************************************************
 * @fn      HalOTAAvail
 *
 * @brief   Determine the space available for downloading an image.
 *
 * @param   None.
 *
 * @return  Number of bytes available for storing an OTA image.
 */
uint32 HalOTAAvail(void)
{
  return HAL_OTA_DL_MAX - HAL_OTA_DL_OSET;
}

#if HAL_OTA_XNV_IS_SPI
/******************************************************************************
 * @fn      xnvSPIWrite
 *
 * @brief   SPI write sequence for code size savings.
 *
 * @param   ch - The byte to write to the SPI.
 *
 * @return  None.
 */
static void xnvSPIWrite(uint8 ch)
{
  XNV_SPI_TX(ch);
  XNV_SPI_WAIT_RXRDY();
}

/******************************************************************************
 * @fn      HalSPIRead
 *
 * @brief   Read from the external NV storage via SPI.
 *
 * @param   addr - Offset into the external NV.
 * @param   pBuf - Pointer to buffer to copy the bytes read from external NV.
 * @param   len - Number of bytes to read from external NV.
 *
 * @return  None.
 *****************************************************************************/
static void HalSPIRead(uint32 addr, uint8 *pBuf, uint16 len)
{
#if !HAL_OTA_BOOT_CODE
  uint8 shdw = P1DIR;
  halIntState_t his;
  HAL_ENTER_CRITICAL_SECTION(his);
  P1DIR |= BV(3);
#endif

  XNV_SPI_BEGIN();
  do
  {
    xnvSPIWrite(XNV_STAT_CMD);
  } while (XNV_SPI_RX() & XNV_STAT_WIP);
  XNV_SPI_END();
  asm("NOP"); asm("NOP");

  XNV_SPI_BEGIN();
  xnvSPIWrite(XNV_READ_CMD);
  xnvSPIWrite(addr >> 16);
  xnvSPIWrite(addr >> 8);
  xnvSPIWrite(addr);
  xnvSPIWrite(0); //for READ DATA BYTES at HIGHER SPEED

  while (len--)
  {
    xnvSPIWrite(0);
    *pBuf++ = XNV_SPI_RX();
  }
  XNV_SPI_END();

#if !HAL_OTA_BOOT_CODE
  P1DIR = shdw;
  HAL_EXIT_CRITICAL_SECTION(his);
#endif
}

/******************************************************************************
 * @fn      HalSPIWrite
 *
 * @brief   Write to the external NV storage via SPI.
 *
 * @param   addr - Offset into the external NV.
 * @param   pBuf - Pointer to the buffer in from which to write bytes to external NV.
 * @param   len - Number of bytes to write to external NV.
 *
 * @return  None.
 *****************************************************************************/
/*
static void HalSPIWrite(uint32 addr, uint8 *pBuf, uint16 len)
{
  uint8 cnt;
  uint32 orig_addr = addr;
#if !HAL_OTA_BOOT_CODE
  uint8 shdw = P1DIR;
  halIntState_t his;
  HAL_ENTER_CRITICAL_SECTION(his);
  P1DIR |= BV(3);
#endif

  while (len)
  {
    XNV_SPI_BEGIN();
    do
    {
      xnvSPIWrite(XNV_STAT_CMD);
    } while (XNV_SPI_RX() & XNV_STAT_WIP);
    XNV_SPI_END();
    asm("NOP"); asm("NOP");

    XNV_SPI_BEGIN();
    xnvSPIWrite(XNV_WREN_CMD);
    XNV_SPI_END();
    asm("NOP"); asm("NOP");

    XNV_SPI_BEGIN();
    xnvSPIWrite(XNV_WRPG_CMD);
    xnvSPIWrite(addr >> 16);
    xnvSPIWrite(addr >> 8);
    xnvSPIWrite(addr);
   
    // Can only write within any one page boundary, so prepare for next page write if bytes remain.
    cnt = 0 - (uint8)addr;

    if (cnt)
    {
      addr += cnt;
    }
    else if(addr != orig_addr)
    {
      addr += 256;
    }
    
    uint32 i=0;
    do
    {
        uint8 raw[4];
        osal_buffer_uint32( raw, addr );
 //       LREP("0x%02X%02X%02X%02X %02X\r\n", raw[3], raw[2],  raw[1], raw[0], pBuf[i]);
        i++;
      xnvSPIWrite(*pBuf++);
      cnt--;
      len--;
    } while (len && cnt);
    
    XNV_SPI_END();  
  }

#if !HAL_OTA_BOOT_CODE
  P1DIR = shdw;
  HAL_EXIT_CRITICAL_SECTION(his);
#endif
}
*/

static void HalSPIWrite(uint32 addr, uint8 *pBuf, uint16 len)
{
#if !HAL_OTA_BOOT_CODE
  uint8 shdw = P1DIR;
  halIntState_t his;
  HAL_ENTER_CRITICAL_SECTION(his);
  P1DIR |= BV(3);
#endif

  while (len > 0)
  {
    XNV_SPI_BEGIN();
    do {
      xnvSPIWrite(XNV_STAT_CMD);
    } while (XNV_SPI_RX() & XNV_STAT_WIP);
    XNV_SPI_END();
    asm("NOP"); asm("NOP");

    XNV_SPI_BEGIN();
    xnvSPIWrite(XNV_WREN_CMD);
    XNV_SPI_END();
    asm("NOP"); asm("NOP");

    XNV_SPI_BEGIN();
    xnvSPIWrite(XNV_WRPG_CMD);
    xnvSPIWrite(addr >> 16);
    xnvSPIWrite(addr >> 8);
    xnvSPIWrite(addr);

    uint16 cnt = 256 - (addr & 0xFF);
    if (cnt > len) cnt = len;

    for (uint16 i = 0; i < cnt; i++) {
      xnvSPIWrite(*pBuf++);
    }

    XNV_SPI_END();

    addr += cnt;
    len -= cnt;
  }

#if !HAL_OTA_BOOT_CODE
  P1DIR = shdw;
  HAL_EXIT_CRITICAL_SECTION(his);
#endif
}


void HalSPIEraseChip(void)
{
    XNV_SPI_BEGIN();
    do
    {
      xnvSPIWrite(XNV_STAT_CMD);
    } while (XNV_SPI_RX() & XNV_STAT_WIP);
    XNV_SPI_END();
    asm("NOP"); asm("NOP");
    
    XNV_SPI_BEGIN();
    xnvSPIWrite(XNV_WREN_CMD);
    XNV_SPI_END();
    asm("NOP"); asm("NOP");

    XNV_SPI_BEGIN();
    xnvSPIWrite(XNV_BE_CMD);
    XNV_SPI_END();
    asm("NOP"); asm("NOP");
    
    XNV_SPI_BEGIN();
    do
    {
      xnvSPIWrite(XNV_STAT_CMD);
    } while (XNV_SPI_RX() & XNV_STAT_WIP);
    XNV_SPI_END();
    asm("NOP"); asm("NOP");
    DelayMs(5000);
}

static void HalSPIEraseSector4K(uint32 addr)
{
    XNV_SPI_BEGIN();
    do
    {
      xnvSPIWrite(XNV_STAT_CMD);
    } while (XNV_SPI_RX() & XNV_STAT_WIP);
    XNV_SPI_END();
    asm("NOP"); asm("NOP");
    
    XNV_SPI_BEGIN();
    xnvSPIWrite(XNV_WREN_CMD);
    XNV_SPI_END();
    asm("NOP"); asm("NOP");

    XNV_SPI_BEGIN();
    xnvSPIWrite(XNV_SE_CMD);
    xnvSPIWrite(addr >> 16);
    xnvSPIWrite(addr >> 8);
    xnvSPIWrite(addr);
    XNV_SPI_END();
    asm("NOP"); asm("NOP");
    
    XNV_SPI_BEGIN();
    do
    {
      xnvSPIWrite(XNV_STAT_CMD);
    } while (XNV_SPI_RX() & XNV_STAT_WIP);
    XNV_SPI_END();
    asm("NOP"); asm("NOP");
    DelayMs(100);
}

static void DelayMs(uint16 delaytime) {
  while(delaytime--)
  {
    uint16 microSecs = 1000;
    while(microSecs--)
    {
      asm("nop"); asm("nop"); asm("nop"); asm("nop"); asm("nop"); asm("nop");
    }
  }
}

#elif !HAL_OTA_XNV_IS_INT
#error Invalid Xtra-NV for OTA.
#endif

/******************************************************************************
*/

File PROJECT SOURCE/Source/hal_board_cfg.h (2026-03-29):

#ifndef HAL_BOARD_CFG_H
#define HAL_BOARD_CFG_H

/* ------------------------------------------------------------------------------------------------
 *                                           Includes
 * ------------------------------------------------------------------------------------------------
 */

#include "hal_mcu.h"
#include "hal_defs.h"
#include "hal_types.h"

/* ------------------------------------------------------------------------------------------------
 *                                          Clock Speed
 * ------------------------------------------------------------------------------------------------
 */

#define HAL_CPU_CLOCK_MHZ     32

/* 32 kHz clock source select in CLKCONCMD */
#if !defined (OSC32K_CRYSTAL_INSTALLED) || (defined (OSC32K_CRYSTAL_INSTALLED) && (OSC32K_CRYSTAL_INSTALLED == TRUE))
#define OSC_32KHZ  0x00 /* external 32 KHz xosc */
#else
#define OSC_32KHZ  0x80 /* internal 32 KHz rcosc */
#endif

#define HAL_CLOCK_STABLE() 

/* ------------------------------------------------------------------------------------------------
 *                                         Key Release detect support
 * ------------------------------------------------------------------------------------------------
 */
#define HAL_KEY_CODE_NOKEY 0xff

/* ------------------------------------------------------------------------------------------------
 *                                       LED Configuration
 * ------------------------------------------------------------------------------------------------
 */

#define HAL_NUM_LEDS            0

#define HAL_LED_BLINK_DELAY()   st( { volatile uint32 i; for (i=0; i<0x5800; i++) { }; } )
#define ACTIVE_LOW        !
#define ACTIVE_HIGH       !!    /* double negation forces result to be '1' */

/* ------------------------------------------------------------------------------------------------
 *                         OSAL NV implemented by internal flash pages.
 * ------------------------------------------------------------------------------------------------
 */

// Flash is partitioned into 8 banks of 32 KB or 16 pages.
#define HAL_FLASH_PAGE_PER_BANK    16
// Flash is constructed of 128 pages of 2 KB.
#define HAL_FLASH_PAGE_SIZE        2048
#define HAL_FLASH_WORD_SIZE        4

// CODE banks get mapped into the XDATA range 8000-FFFF.
#define HAL_FLASH_PAGE_MAP         0x8000

// The last 16 bytes of the last available page are reserved for flash lock bits.
// NV page definitions must coincide with segment declaration in project *.xcl file.
#if defined NON_BANKED
#define HAL_FLASH_LOCK_BITS        16
#define HAL_NV_PAGE_END            30
#define HAL_NV_PAGE_CNT            2
#else
#define HAL_FLASH_LOCK_BITS        16
#define HAL_NV_PAGE_END            126
#define HAL_NV_PAGE_CNT            6
#endif

// Re-defining Z_EXTADDR_LEN here so as not to include a Z-Stack .h file.
#define HAL_FLASH_IEEE_SIZE        8
#define HAL_FLASH_IEEE_PAGE       (HAL_NV_PAGE_END+1)
#define HAL_FLASH_IEEE_OSET       (HAL_FLASH_PAGE_SIZE - HAL_FLASH_LOCK_BITS - HAL_FLASH_IEEE_SIZE)
#define HAL_INFOP_IEEE_OSET        0xC

#define HAL_FLASH_DEV_PRIVATE_KEY_OSET     0x7D2
#define HAL_FLASH_CA_PUBLIC_KEY_OSET       0x7BC
#define HAL_FLASH_IMPLICIT_CERT_OSET       0x78C

#define HAL_NV_PAGE_BEG           (HAL_NV_PAGE_END-HAL_NV_PAGE_CNT+1)
// Used by DMA macros to shift 1 to create a mask for DMA registers.
#define HAL_NV_DMA_CH              0
#define HAL_DMA_CH_RX              3
#define HAL_DMA_CH_TX              4

#define HAL_NV_DMA_GET_DESC()      HAL_DMA_GET_DESC0()
#define HAL_NV_DMA_SET_ADDR(a)     HAL_DMA_SET_ADDR_DESC0((a))

/* ------------------------------------------------------------------------------------------------
 *  Serial Boot Loader: reserving the first 4 pages of flash and other memory in cc2530-sb.xcl.
 * ------------------------------------------------------------------------------------------------
 */

#define HAL_SB_IMG_ADDR       0x2000
#define HAL_SB_CRC_ADDR       0x2090
// Size of internal flash less 4 pages for boot loader, 6 pages for NV, & 1 page for lock bits.
#define HAL_SB_IMG_SIZE      (0x40000 - 0x2000 - 0x3000 - 0x0800)

/* ------------------------------------------------------------------------------------------------
 *                                            Macros
 * ------------------------------------------------------------------------------------------------
 */

/* ----------- RF-frontend Connection Initialization ---------- */
#ifdef HAL_PA_LNA_CC2592
extern void MAC_RfFrontendSetup(void);
#define HAL_BOARD_RF_FRONTEND_SETUP() MAC_RfFrontendSetup()
#else
#define HAL_BOARD_RF_FRONTEND_SETUP()
#endif

/* ------------------------------------------------------------------------------------------------
 *                                            Macros
 * ------------------------------------------------------------------------------------------------
 */

#define CLKCONCMD_VALUE (CLKCONCMD_32MHZ | OSC_32KHZ)
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

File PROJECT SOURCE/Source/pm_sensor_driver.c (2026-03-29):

/*********************************************************************
 * INCLUDES
 *********************************************************************/

#include "pm_sensor_driver.h"
#include "hal_i2c.h"
#include <stdlib.h>

/*********************************************************************
 * CONSTANTS
 *********************************************************************/

// I2C addresses
#define SENSOR_ADDR             0x08
#define APM_ADDR_READ           ((SENSOR_ADDR << 1) | 0x01)  // 0x11
#define APM_ADDR_WRITE          ((SENSOR_ADDR << 1) | 0x00)  // 0x10

// Command lengths
#define START_CMD_LENGTH        5
#define STOP_CMD_LENGTH         2
#define READ_CMD_LENGTH         2

// Command data
static const uint8_t start_command[START_CMD_LENGTH] = {0x00, 0x10, 0x05, 0x00, 0xF6};
static const uint8_t stop_command[STOP_CMD_LENGTH] = {0x01, 0x04};
static const uint8_t read_command[READ_CMD_LENGTH] = {0x03, 0x00};

/*********************************************************************
 * LOCAL VARIABLES
 *********************************************************************/

// Current sensor type
static sensor_type_t current_sensor = SENSOR_TYPE_UNKNOWN;

/*********************************************************************
 * LOCAL FUNCTIONS PROTOTYPES
 *********************************************************************/

static uint8_t calc_crc8(uint8_t* data, uint8_t length);
static sensor_type_t detect_sensor(void);
static bool read_apm10(uint16_t* pm1, uint16_t* pm2_5, uint16_t* pm10);
static bool read_apm2000(uint16_t* pm1, uint16_t* pm2_5, uint16_t* pm10);

// Delay function (declared in zcl_app.c)
extern void DelayMs(unsigned int delaytime);

/*********************************************************************
 * @fn      calc_crc8
 *
 * @brief   CRC8 calculation for APM2000 sensor
 *********************************************************************/

static uint8_t calc_crc8(uint8_t* data, uint8_t length)
{
    uint8_t crc = 0xFF;
    uint8_t i, bit;
    
    for (i = 0; i < length; i++) {
        crc ^= data[i];
        for (bit = 0; bit < 8; bit++) {
            if (crc & 0x80) {
                crc = (crc << 1) ^ 0x31;
            } else {
                crc = crc << 1;
            }
        }
    }
    return crc;
}

/*********************************************************************
 * @fn      detect_sensor
 *
 * @brief   Detect connected sensor type (APM10 or APM2000)
 *********************************************************************/

static sensor_type_t detect_sensor(void)
{
    uint8_t test_data[30] = {0};
    int i;
    
    // Send read command
    HalI2CSend(APM_ADDR_WRITE, (uint8_t*)read_command, READ_CMD_LENGTH);
    
    // Try to read 30 bytes (maximum format)
    HalI2CReceive(APM_ADDR_READ, test_data, 30);
    
    // Check for APM2000: CRC bytes present and data non-zero
    bool has_nonzero = false;
    for (i = 0; i < 30; i++) {
        if (test_data[i] != 0) {
            has_nonzero = true;
            break;
        }
    }
    
    if (has_nonzero) {
        // Check CRC for APM2000
        uint8_t crc_buf[2];
        
        // Check PM1 CRC
        crc_buf[0] = test_data[0];
        crc_buf[1] = test_data[1];
        if (calc_crc8(crc_buf, 2) == test_data[2]) {
            return SENSOR_TYPE_APM2000;
        }
        
        // Check PM2.5 CRC
        crc_buf[0] = test_data[3];
        crc_buf[1] = test_data[4];
        if (calc_crc8(crc_buf, 2) == test_data[5]) {
            return SENSOR_TYPE_APM2000;
        }
    }
    
    // Check for APM10: first 12 bytes contain data
    uint16_t pm1 = (test_data[0] << 8) | test_data[1];
    uint16_t pm2_5 = (test_data[3] << 8) | test_data[4];
    uint16_t pm10 = (test_data[9] << 8) | test_data[10];
    
    if (pm1 != 0 || pm2_5 != 0 || pm10 != 0) {
        return SENSOR_TYPE_APM10;
    }
    
    return SENSOR_TYPE_UNKNOWN;
}

/*********************************************************************
 * @fn      read_apm10
 *
 * @brief   Read data from APM10 sensor
 *********************************************************************/

static bool read_apm10(uint16_t* pm1, uint16_t* pm2_5, uint16_t* pm10)
{
    uint8_t data[12] = {0};
    
    HalI2CSend(APM_ADDR_WRITE, (uint8_t*)read_command, READ_CMD_LENGTH);
    HalI2CReceive(APM_ADDR_READ, data, 12);
    
    *pm1 = (data[0] << 8) | data[1];
    *pm2_5 = (data[3] << 8) | data[4];
    *pm10 = (data[9] << 8) | data[10];
    
    return (*pm1 != 0xFFFF && *pm2_5 != 0xFFFF && *pm10 != 0xFFFF);
}

/*********************************************************************
 * @fn      read_apm2000
 *
 * @brief   Read data from APM2000 sensor with CRC validation
 *********************************************************************/

static bool read_apm2000(uint16_t* pm1, uint16_t* pm2_5, uint16_t* pm10)
{
    uint8_t data[30] = {0};
    uint8_t crc_buf[2];
    
    HalI2CSend(APM_ADDR_WRITE, (uint8_t*)read_command, READ_CMD_LENGTH);
    HalI2CReceive(APM_ADDR_READ, data, 30);
    
    // PM1
    crc_buf[0] = data[0];
    crc_buf[1] = data[1];
    if (calc_crc8(crc_buf, 2) == data[2]) {
        *pm1 = (data[0] << 8) | data[1];
    } else {
        *pm1 = 0xFFFF;
    }
    
    // PM2.5
    crc_buf[0] = data[3];
    crc_buf[1] = data[4];
    if (calc_crc8(crc_buf, 2) == data[5]) {
        *pm2_5 = (data[3] << 8) | data[4];
    } else {
        *pm2_5 = 0xFFFF;
    }
    
    // PM10
    crc_buf[0] = data[9];
    crc_buf[1] = data[10];
    if (calc_crc8(crc_buf, 2) == data[11]) {
        *pm10 = (data[9] << 8) | data[10];
    } else {
        *pm10 = 0xFFFF;
    }
    
    return (*pm1 != 0xFFFF && *pm2_5 != 0xFFFF && *pm10 != 0xFFFF);
}

/*********************************************************************
 * PUBLIC FUNCTIONS
 *********************************************************************/

/*********************************************************************
 * @fn      sensor_init
 *
 * @brief   Initialize sensor with auto-detection
 *********************************************************************/

void sensor_init(void)
{
    HalI2CInit();
    DelayMs(2500);
    
    // Send start command
    HalI2CSend(APM_ADDR_WRITE, (uint8_t*)start_command, START_CMD_LENGTH);
    DelayMs(2500);
    
    // Detect sensor type
    current_sensor = detect_sensor();
    
    // Small delay after detection
    DelayMs(100);
}

/*********************************************************************
 * @fn      sensor_read
 *
 * @brief   Read data from detected sensor
 *********************************************************************/

bool sensor_read(uint16_t* pm1, uint16_t* pm2_5, uint16_t* pm10)
{
    if (current_sensor == SENSOR_TYPE_APM10) {
        return read_apm10(pm1, pm2_5, pm10);
    } else if (current_sensor == SENSOR_TYPE_APM2000) {
        return read_apm2000(pm1, pm2_5, pm10);
    }
    
    return false;
}
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

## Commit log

2025-05-21 backlight brightness
    fixed the procedure for setting the backlight brightness at device startup
2025-06-02 Changed initialization of the voltmeter needle.
